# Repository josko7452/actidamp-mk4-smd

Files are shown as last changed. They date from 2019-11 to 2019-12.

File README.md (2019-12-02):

# Actidamp Mk. IV - SMD

Low noise RIAA preamplifier with JFET input and active input impedance (to mitigate Johnson noise)

## Schematics

* **Main board** - [pdf link](https://github.com/josko7452/actidamp-mk4-smd/releases/download/2019.11.5/main-pcb.pdf)
* **Power supply** - [pdf link](https://github.com/josko7452/actidamp-mk4-smd/releases/download/2019.11.5/psu-brick.pdf)
* **Front & Back panel** - [pdf link](https://github.com/josko7452/actidamp-mk4-smd/releases/download/2019.11.5/panels.pdf)

## Pictures

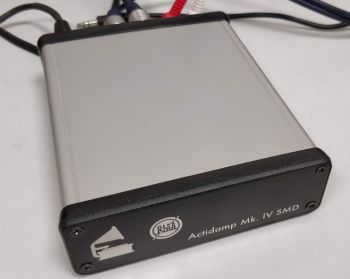
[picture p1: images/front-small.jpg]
front

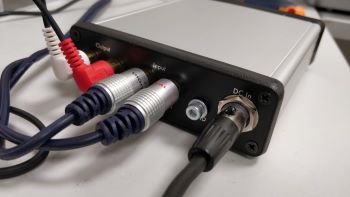
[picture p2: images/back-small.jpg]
back

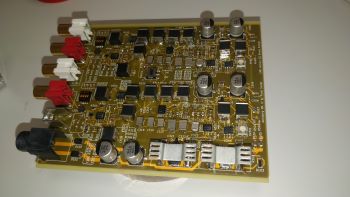
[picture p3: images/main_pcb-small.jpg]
main-pcb

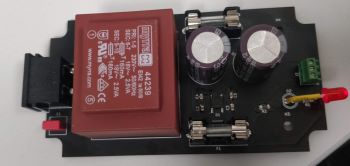
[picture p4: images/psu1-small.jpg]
psu1

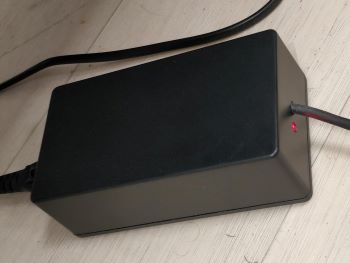
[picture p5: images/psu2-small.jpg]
psu2


## Getting Started

To build this just download Gerbers from release page and hand-off to your favourtie PCB manufacturer.
I have tested it with JLC PCB. But it has no crazy requirements besides the mainboard is 4 layer.

(If you want BOM, download KiCad and generate it from the Schematic, you will likely change parts anyway
dependig on accessibility.. you can shoot me a message and I will send you the Mouser part list from
my order history if you wish)

## Structure

There are 3 KiCad project for each PCB. i.e. *'main-pcb'*, *'panels'* and *'psu-brick'*.
Also there is LTSpice simulation in 'ltspice' subfolder.
Other than that it also cointains KiCad libraries used as submodules (kicad-footprints and kicad-symbols)

## Authors

* **Pavel Dudek** - *Original THT version* - [Amaterske radio 94-06](https://archive.org/stream/Amaterske_radio_1994/94-06#page/n19)
* **Bruno Kremel [me]** - *Modified to SMD and using different JFET*

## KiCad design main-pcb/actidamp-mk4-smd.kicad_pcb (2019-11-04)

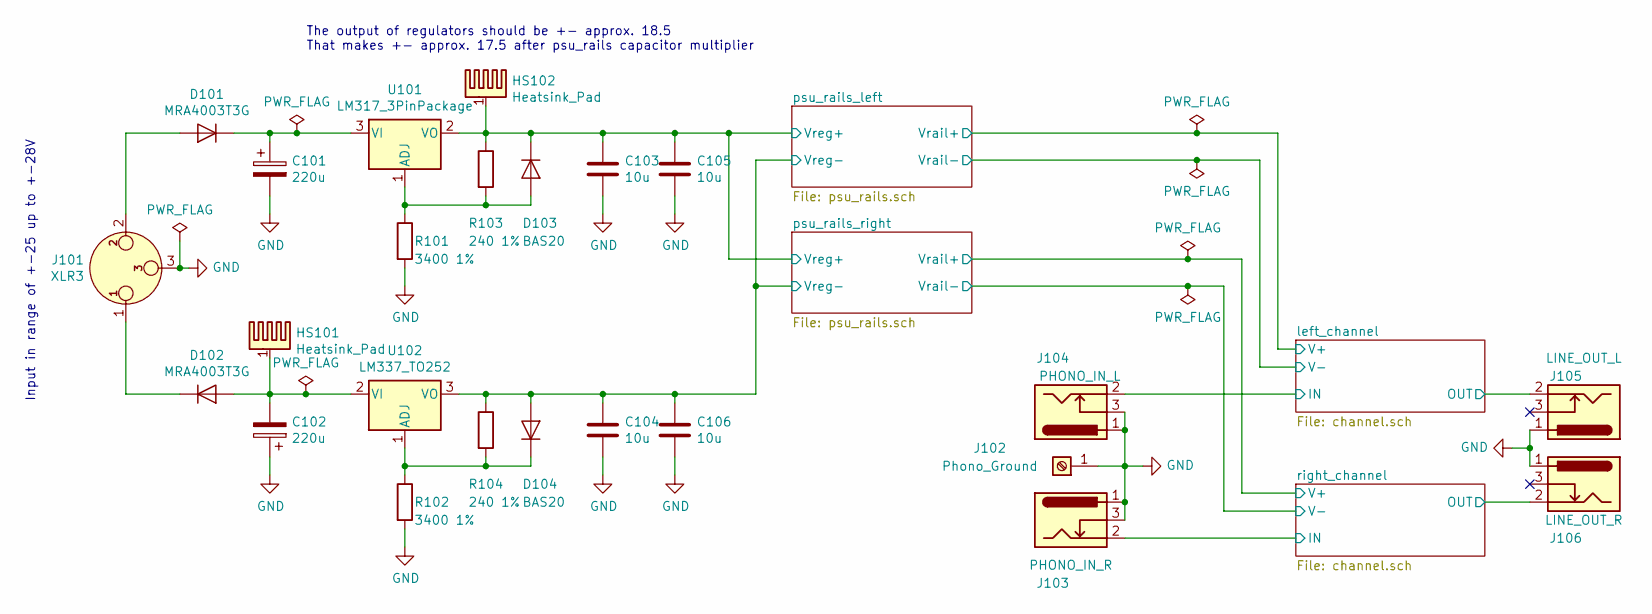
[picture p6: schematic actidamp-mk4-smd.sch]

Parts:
C101, C102: 220u; CP_Elec_8x10.5; Part number EEE1EA221UP
C103, C104, C105, C106: 10u; C_1206_3216Metric_Pad1.42x1.75mm_HandSolder; Part number C1206C106K3PACTU
D101, D102: MRA4003T3G; D_SMA; Part number MRA4003T3G
D103, D104: BAS20; D_SOT-23_ANK; Part number BAS20
HS101, HS102: Heatsink_Pad; Heatsink_TO252_573100; Part number FK 244 13 D PAK
J101: XLR3; MiniXLR_TRAPC3M1X; Part number TRAPC3MX
J102: Phono_Ground; SCREW_TERMINAL_SCTM4RA; Part number SCRTM4RA
J103: PHONO_IN_L; RCA_x1_PJRAN1X1U; Part number PJRAN1X1U02AUX
J104: PHONO_IN_R; RCA_x1_PJRAN1X1U; Part number PJRAN1X1U03AUX
J105: LINE_OUT_L; RCA_x1_PJRAN1X1U; Part number PJRAN1X1U02AUX
J106: LINE_OUT_R; RCA_x1_PJRAN1X1U; Part number PJRAN1X1U03AUX
R101, R102: 3400 1%; R_0603_1608Metric_Pad1.05x0.95mm_HandSolder; Part number MCWF06R3401BTL
R103, R104: 240 1%; R_0603_1608Metric_Pad1.05x0.95mm_HandSolder; Part number ERA3AEB241V
U101: LM317_3PinPackage; TO-252-3_TabPin2; Part number LM317MDTX
U102: LM337_TO252; TO-252-3_TabPin2; Part number LM337KVURG3

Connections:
/left_channel/IN: J103.2; also elsewhere on the board
/left_channel/OUT: J105.2; also elsewhere on the board
/psu_rails_left/Vreg+: C103.1, C105.1, D103.1 (K), HS102.1, R103.1, U101.2 (VO); also elsewhere on the board
/psu_rails_left/Vreg-: C104.2, C106.2, D104.2 (A), R104.1, U102.3 (VO); also elsewhere on the board
/right_channel/IN: J104.2; also elsewhere on the board
/right_channel/OUT: J106.2; also elsewhere on the board
GND: C101.2, C102.1, C103.2, C104.1, C105.2, C106.1, J101.3, J102.1, J103.1, J103.3, J104.1, J104.3, J105.1, J106.1, R101.2, R102.2; also elsewhere on the board
unnamed: C101.1, D101.1 (K), U101.3 (VI)
unnamed: C102.2, D102.2 (A), HS101.1, U102.2 (VI)
unnamed: D101.2 (A), J101.2
unnamed: D102.1 (K), J101.1
unnamed: D103.2 (A), R101.1, R103.2, U101.1 (ADJ)
unnamed: D104.1 (K), R102.1, R104.2, U102.1 (ADJ)

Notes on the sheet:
The output of regulators should be +- approx. 18.5 That makes +- approx. 17.5 after psu_rails capacitor multiplier
Input in range of +-25 up to +-28V

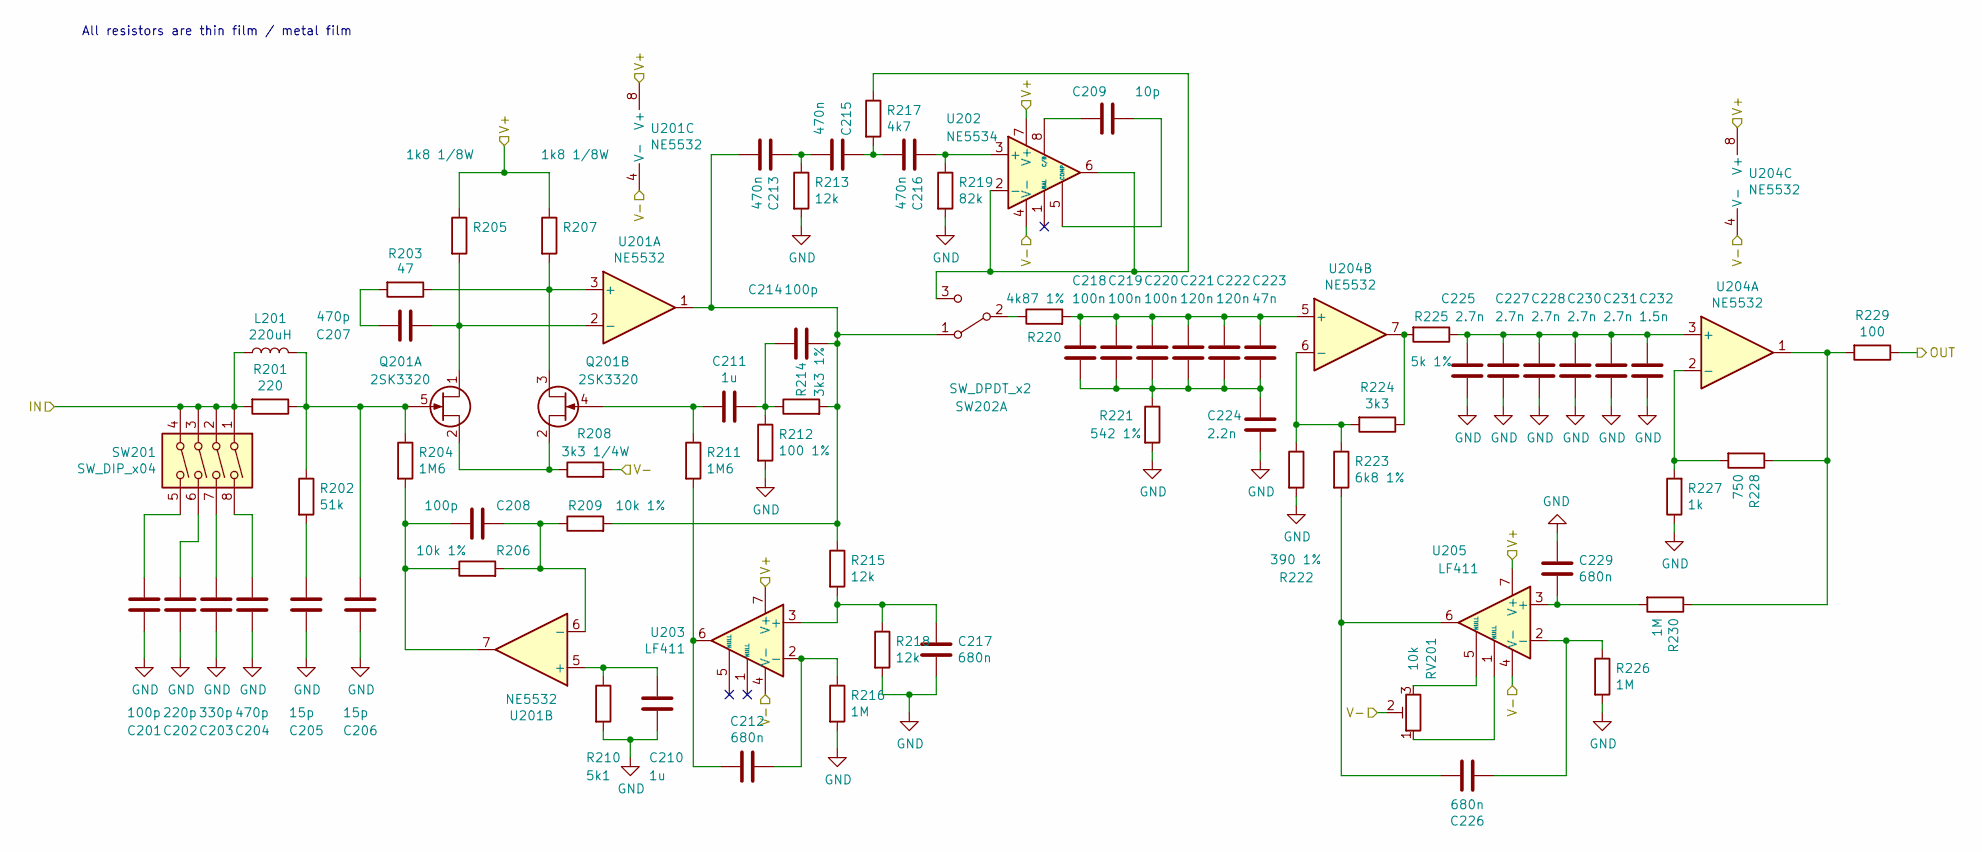
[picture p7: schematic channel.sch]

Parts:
C201, C208, C214: 100p; C_0603_1608Metric_Pad1.05x0.95mm_HandSolder; Part number MC0603N101J500CT
C202: 220p; C_0603_1608Metric_Pad1.05x0.95mm_HandSolder; Part number 06035A221JAT2A
C203: 330p; C_0603_1608Metric_Pad1.05x0.95mm_HandSolder; Part number MC0603N331J500CT
C204, C207: 470p; C_0603_1608Metric_Pad1.05x0.95mm_HandSolder; Part number VJ0603A471JXACW1BC
C205, C206: 15p; C_0603_1608Metric_Pad1.05x0.95mm_HandSolder; Part number MC0603N150J500CT
C209: 10p; C_0603_1608Metric_Pad1.05x0.95mm_HandSolder; Part number MC0603N100J500CT
C210, C211: 1u; C_2824_7260Metric_Pad3.20x4.45mm_HandSolder; Part number SMDIC04100TB00KQ00
C212, C217, C226, C229: 680n; C_2824_7260Metric_Pad3.20x4.45mm_HandSolder; Part number SMDIC03680TB00KQ00
C213, C215, C216: 470n; C_2824_7260Metric_Pad3.20x4.45mm_HandSolder; Part number SMDIC03470TB00MQ00
C218, C219, C220: 100n; C_1913_4833Metric_Pad1.3x3.00mm_HandSolder; Part number ECHU1H104GX9
C221, C222: 120n; C_2416_6041Metric_Pad1.5x3.8mm_HandSolder; Part number ECHU1H124GX9
C223: 47n; C_1913_4833Metric_Pad1.3x3.00mm_HandSolder; Part number ECHU1H473GX9
C224: 2.2n; C_0805_2012Metric_Pad1.15x1.1mm_HandSolder; Part number ECHU1H222GX5
C225, C227, C228, C230, C231: 2.7n; C_0805_2012Metric_Pad1.15x1.1mm_HandSolder; Part number ECHU1H272GX5
C232: 1.5n; C_0805_2012Metric_Pad1.15x1.1mm_HandSolder; Part number ECHU1H152GX5
L201: 220uH; L_NLFV32_Pad1.2x2.0mm_HandSolder; Part number NLFV32T-221K-EF
Q201: 2SK3320; SOT-353_SC-70-5_Handsoldering; Part number 2SK3320
R201: 220; R_0603_1608Metric_Pad1.05x0.95mm_HandSolder; Part number ERA3AEB221V
R202: 51k; R_0603_1608Metric_Pad1.05x0.95mm_HandSolder; Part number ERA3AEB513V
R203: 47; R_0603_1608Metric_Pad1.05x0.95mm_HandSolder; Part number RT0603FRE0747RL
R204, R211: 1M6; R_0805_2012Metric_Pad1.15x1.40mm_HandSolder; Part number 1-1614959-2
R205, R207: 1k8 1/8W; R_0805_2012Metric_Pad1.15x1.40mm_HandSolder; Part number RT0805FRE071K8L
R206, R209: 10k 1%; R_0603_1608Metric_Pad1.05x0.95mm_HandSolder; Part number RT0603WRE0710KL
R208: 3k3 1/4W; R_1206_3216Metric_Pad1.42x1.75mm_HandSolder; Part number ERA8ARB332V
R210: 5k1; R_0603_1608Metric_Pad1.05x0.95mm_HandSolder; Part number ERA3AEB512V
R212: 100 1%; R_0603_1608Metric_Pad1.05x0.95mm_HandSolder; Part number RT0603FRE07100RL
R213, R215, R218: 12k; R_0603_1608Metric_Pad1.05x0.95mm_HandSolder; Part number ERA3AEB123V
R214: 3k3 1%; R_0603_1608Metric_Pad1.05x0.95mm_HandSolder; Part number RT0603FRE073K3L
R216, R226, R230: 1M; R_0603_1608Metric_Pad1.05x0.95mm_HandSolder; Part number MCT06030C1004FP500
R217: 4k7; R_0603_1608Metric_Pad1.05x0.95mm_HandSolder; Part number RT0603FRE074K7L
R219: 82k; R_0603_1608Metric_Pad1.05x0.95mm_HandSolder; Part number ERA3AEB823V
R220: 4k87 1%; R_0603_1608Metric_Pad1.05x0.95mm_HandSolder; Part number CPF0603F4K87C1
R221: 542 1%; R_0603_1608Metric_Pad1.05x0.95mm_HandSolder; Part number RN73H1JTTD5420B50
R222: 390 1%; R_0603_1608Metric_Pad1.05x0.95mm_HandSolder; Part number RT0603FRE07390RL
R223: 6k8 1%; R_0603_1608Metric_Pad1.05x0.95mm_HandSolder; Part number RT0603FRE076K8L
R224: 3k3; R_0603_1608Metric_Pad1.05x0.95mm_HandSolder; Part number RT0603FRE073K3L
R225: 5k 1%; R_0603_1608Metric_Pad1.05x0.95mm_HandSolder; Part number RT0603BRE075KL
R227: 1k; R_0603_1608Metric_Pad1.05x0.95mm_HandSolder; Part number RT0603FRE071KL
R228: 750; R_0603_1608Metric_Pad1.05x0.95mm_HandSolder; Part number MCT06030C7500FP500
R229: 100; R_0603_1608Metric_Pad1.05x0.95mm_HandSolder; Part number MCT06030C1000FP500
RV201: 10k; Potentiometer_Vishay_TS53YJ_Vertical; Part number TS53YJ103MR10
SW201: SW_DIP_x04; SW_DIP_SPSTx04_Slide_TE_1571983-5_W6.2mm_P1.27mm; Part number 1571983-5
SW202: SW_DPDT_x2; Wurth_452403012014; Part number 452403012014
U201, U204: NE5532; SOIC-8_3.9x4.9mm_P1.27mm; Part number NE5532DR
U202: NE5534; SOIC-8_3.9x4.9mm_P1.27mm; Part number NE5534ADG
U203, U205: LF411; SOIC-8_3.9x4.9mm_P1.27mm; Part number LF411CD

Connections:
/left_channel/IN: L201.1, R201.2, SW201.1, SW201.2, SW201.3, SW201.4; also elsewhere on the board
/left_channel/OUT: R229.1; also elsewhere on the board
/left_channel/V+: R205.1, R207.1, U201.8 (V+), U202.7 (V+), U203.7 (V+), U204.8 (V+), U205.7 (V+); also elsewhere on the board
/left_channel/V-: R208.2, RV201.2, U201.4 (V-), U202.4 (V-), U203.4 (V-), U204.4 (V-), U205.4 (V-); also elsewhere on the board
GND: C201.2, C202.2, C203.2, C204.2, C205.2, C206.2, C210.2, C217.2, C224.2, C225.2, C227.2, C228.2, C229.1, C230.2, C231.2, C232.2, R210.2, R212.2, R213.2, R216.2, R218.2, R219.2, R221.2, R222.2, R226.2, R227.1; also elsewhere on the board
unnamed: C201.1, SW201.5
unnamed: C202.1, SW201.6
unnamed: C203.1, SW201.7
unnamed: C204.1, SW201.8
unnamed: C205.1, R202.2
unnamed: C206.1, L201.2, Q201.5 (G), R201.1, R202.1, R204.1
unnamed: C207.1, Q201.1 (D), R205.2, U201.2 (-)
unnamed: C207.2, R203.2
unnamed: C208.1, R206.2, R209.1, U201.6 (-)
unnamed: C208.2, R204.2, R206.1, U201.7
unnamed: C209.1, U202.5 (COMP)
unnamed: C209.2, U202.8 (C/B)
unnamed: C210.1, R210.1, U201.5 (+)
unnamed: C211.1, C214.2, R212.1, R214.1
unnamed: C211.2, Q201.4 (G), R211.1
unnamed: C212.1, R216.1, U203.2 (-)
unnamed: C212.2, R211.2, U203.6
unnamed: C213.1, C215.2, R213.1
unnamed: C213.2, C214.1, R209.2, R214.2, R215.1, SW202.1 (A), U201.1
unnamed: C215.1, C216.2, R217.2
unnamed: C216.1, R219.1, U202.3 (+)
unnamed: C217.1, R215.2, R218.1, U203.3 (+)
unnamed: C218.1, C219.1, C220.1, C221.1, C222.1, C223.1, R220.2, U204.5 (+)
unnamed: C218.2, C219.2, C220.2, C221.2, C222.2, C223.2, C224.1, R221.1
unnamed: C225.1, C227.1, C228.1, C230.1, C231.1, C232.1, R225.1, U204.3 (+)
unnamed: C226.1, R223.2, U205.6
unnamed: C226.2, R226.1, U205.2 (-)
unnamed: C229.2, R230.2, U205.3 (+)
unnamed 59: SW202.4 (A); also elsewhere on the board
unnamed: Q201.2 (S), R208.1
unnamed: Q201.3 (D), R203.1, R207.2, U201.3 (+)
unnamed: R217.1, SW202.3 (C), U202.2 (-), U202.6
unnamed: R220.1, SW202.2 (B)
unnamed: R222.1, R223.1, R224.2, U204.6 (-)
unnamed: R224.1, R225.2, U204.7
unnamed: R227.2, R228.2, U204.2 (-)
unnamed: R228.1, R229.2, R230.1, U204.1
unnamed 97: SW202.6 (C); also elsewhere on the board
unnamed 98: SW202.5 (B); also elsewhere on the board
unnamed: RV201.1, U205.1 (NULL)
unnamed: RV201.3, U205.5 (NULL)

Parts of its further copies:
C301, C308, C314: 100p; C_0603_1608Metric_Pad1.05x0.95mm_HandSolder; Part number MC0603N101J500CT
C302: 220p; C_0603_1608Metric_Pad1.05x0.95mm_HandSolder; Part number 06035A221JAT2A
C303: 330p; C_0603_1608Metric_Pad1.05x0.95mm_HandSolder; Part number MC0603N331J500CT
C304, C307: 470p; C_0603_1608Metric_Pad1.05x0.95mm_HandSolder; Part number VJ0603A471JXACW1BC
C305, C306: 15p; C_0603_1608Metric_Pad1.05x0.95mm_HandSolder; Part number MC0603N150J500CT
C309: 10p; C_0603_1608Metric_Pad1.05x0.95mm_HandSolder; Part number MC0603N100J500CT
C310, C311: 1u; C_2824_7260Metric_Pad3.20x4.45mm_HandSolder; Part number SMDIC04100TB00KQ00
C312, C317, C326, C329: 680n; C_2824_7260Metric_Pad3.20x4.45mm_HandSolder; Part number SMDIC03680TB00KQ00
C313, C315, C316: 470n; C_2824_7260Metric_Pad3.20x4.45mm_HandSolder; Part number SMDIC03470TB00MQ00
C318, C319, C320: 100n; C_1913_4833Metric_Pad1.3x3.00mm_HandSolder; Part number ECHU1H104GX9
C321, C322: 120n; C_2416_6041Metric_Pad1.5x3.8mm_HandSolder; Part number ECHU1H124GX9
C323: 47n; C_1913_4833Metric_Pad1.3x3.00mm_HandSolder; Part number ECHU1H473GX9
C325, C327, C328, C330, C331: 2.7n; C_0805_2012Metric_Pad1.15x1.1mm_HandSolder; Part number ECHU1H272GX5
C332: 1.5n; C_0805_2012Metric_Pad1.15x1.1mm_HandSolder; Part number ECHU1H152GX5
L301: 220uH; L_NLFV32_Pad1.2x2.0mm_HandSolder; Part number NLFV32T-221K-EF
Q301: 2SK3320; SOT-353_SC-70-5_Handsoldering; Part number 2SK3320
R301: 220; R_0603_1608Metric_Pad1.05x0.95mm_HandSolder; Part number ERA3AEB221V
R302: 51k; R_0603_1608Metric_Pad1.05x0.95mm_HandSolder; Part number ERA3AEB513V
R303: 47; R_0603_1608Metric_Pad1.05x0.95mm_HandSolder; Part number RT0603FRE0747RL
R304, R311: 1M6; R_0805_2012Metric_Pad1.15x1.40mm_HandSolder; Part number 1-1614959-2
R305, R307: 1k8 1/8W; R_0805_2012Metric_Pad1.15x1.40mm_HandSolder; Part number RT0805FRE071K8L
R306, R309: 10k 1%; R_0603_1608Metric_Pad1.05x0.95mm_HandSolder; Part number RT0603WRE0710KL
R308: 3k3 1/4W; R_1206_3216Metric_Pad1.42x1.75mm_HandSolder; Part number ERA8ARB332V
R310: 5k1; R_0603_1608Metric_Pad1.05x0.95mm_HandSolder; Part number ERA3AEB512V
R312: 100 1%; R_0603_1608Metric_Pad1.05x0.95mm_HandSolder; Part number RT0603FRE07100RL
R313, R315, R318: 12k; R_0603_1608Metric_Pad1.05x0.95mm_HandSolder; Part number ERA3AEB123V
R314: 3k3 1%; R_0603_1608Metric_Pad1.05x0.95mm_HandSolder; Part number RT0603FRE073K3L
R316, R326, R330: 1M; R_0603_1608Metric_Pad1.05x0.95mm_HandSolder; Part number MCT06030C1004FP500
R317: 4k7; R_0603_1608Metric_Pad1.05x0.95mm_HandSolder; Part number RT0603FRE074K7L
R319: 82k; R_0603_1608Metric_Pad1.05x0.95mm_HandSolder; Part number ERA3AEB823V
R320: 4k87 1%; R_0603_1608Metric_Pad1.05x0.95mm_HandSolder; Part number CPF0603F4K87C1
R321: 542 1%; R_0603_1608Metric_Pad1.05x0.95mm_HandSolder; Part number RN73H1JTTD5420B50
R322: 390 1%; R_0603_1608Metric_Pad1.05x0.95mm_HandSolder; Part number RT0603FRE07390RL
R323: 6k8 1%; R_0603_1608Metric_Pad1.05x0.95mm_HandSolder; Part number RT0603FRE076K8L
R324: 3k3; R_0603_1608Metric_Pad1.05x0.95mm_HandSolder; Part number RT0603FRE073K3L
R325: 5k 1%; R_0603_1608Metric_Pad1.05x0.95mm_HandSolder; Part number RT0603BRE075KL
R327: 1k; R_0603_1608Metric_Pad1.05x0.95mm_HandSolder; Part number RT0603FRE071KL
R328: 750; R_0603_1608Metric_Pad1.05x0.95mm_HandSolder; Part number MCT06030C7500FP500
R329: 100; R_0603_1608Metric_Pad1.05x0.95mm_HandSolder; Part number MCT06030C1000FP500
RV301: 10k; Potentiometer_Vishay_TS53YJ_Vertical; Part number TS53YJ103MR10
SW301: SW_DIP_x04; SW_DIP_SPSTx04_Slide_TE_1571983-5_W6.2mm_P1.27mm; Part number 1571983-5
U301, U304: NE5532; SOIC-8_3.9x4.9mm_P1.27mm; Part number NE5532DR
U302: NE5534; SOIC-8_3.9x4.9mm_P1.27mm; Part number NE5534ADG
U303, U305: LF411; SOIC-8_3.9x4.9mm_P1.27mm; Part number LF411CD

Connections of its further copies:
/right_channel/IN: L301.1, R301.2, SW301.1, SW301.2, SW301.3, SW301.4; also elsewhere on the board
/right_channel/OUT: R329.1; also elsewhere on the board
/right_channel/V+: R305.1, R307.1, U301.8 (V+), U302.7 (V+), U303.7 (V+), U304.8 (V+), U305.7 (V+); also elsewhere on the board
/right_channel/V-: R308.2, RV301.2, U301.4 (V-), U302.4 (V-), U303.4 (V-), U304.4 (V-), U305.4 (V-); also elsewhere on the board
GND: C301.2, C302.2, C303.2, C304.2, C305.2, C306.2, C310.2, C317.2, C325.2, C327.2, C328.2, C329.1, C330.2, C331.2, C332.2, R310.2, R312.2, R313.2, R316.2, R318.2, R319.2, R321.2, R322.2, R326.2, R327.1; also elsewhere on the board
unnamed: C301.1, SW301.5
unnamed: C302.1, SW301.6
unnamed: C303.1, SW301.7
unnamed: C304.1, SW301.8
unnamed: C305.1, R302.2
unnamed: C306.1, L301.2, Q301.5 (G), R301.1, R302.1, R304.1
unnamed: C307.1, Q301.1 (D), R305.2, U301.2 (-)
unnamed: C307.2, R303.2
unnamed: C308.1, R306.2, R309.1, U301.6 (-)
unnamed: C308.2, R304.2, R306.1, U301.7
unnamed: C309.1, U302.5 (COMP)
unnamed: C309.2, U302.8 (C/B)
unnamed: C310.1, R310.1, U301.5 (+)
unnamed: C311.1, C314.2, R312.1, R314.1
unnamed: C311.2, Q301.4 (G), R311.1
unnamed: C312.1, R316.1, U303.2 (-)
unnamed: C312.2, R311.2, U303.6
unnamed: C313.1, C315.2, R313.1
unnamed 59: C313.2, C314.1, R309.2, R314.2, R315.1, U301.1; also elsewhere on the board
unnamed: C315.1, C316.2, R317.2
unnamed: C316.1, R319.1, U302.3 (+)
unnamed: C317.1, R315.2, R318.1, U303.3 (+)
unnamed: C318.1, C319.1, C320.1, C321.1, C322.1, C323.1, R320.2, U304.5 (+)
unnamed 64: C318.2, C319.2, C320.2, C321.2, C322.2, C323.2, R321.1; also elsewhere on the board
unnamed: C325.1, C327.1, C328.1, C330.1, C331.1, C332.1, R325.1, U304.3 (+)
unnamed: C326.1, R323.2, U305.6
unnamed: C326.2, R326.1, U305.2 (-)
unnamed: C329.2, R330.2, U305.3 (+)
unnamed: Q301.2 (S), R308.1
unnamed: Q301.3 (D), R303.1, R307.2, U301.3 (+)
unnamed 97: R317.1, U302.2 (-), U302.6; also elsewhere on the board
unnamed 98: R320.1; also elsewhere on the board
unnamed: R322.1, R323.1, R324.2, U304.6 (-)
unnamed: R324.1, R325.2, U304.7
unnamed: R327.2, R328.2, U304.2 (-)
unnamed: R328.1, R329.2, R330.1, U304.1
unnamed: RV301.1, U305.1 (NULL)
unnamed: RV301.3, U305.5 (NULL)

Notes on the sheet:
All resistors are thin film / metal film

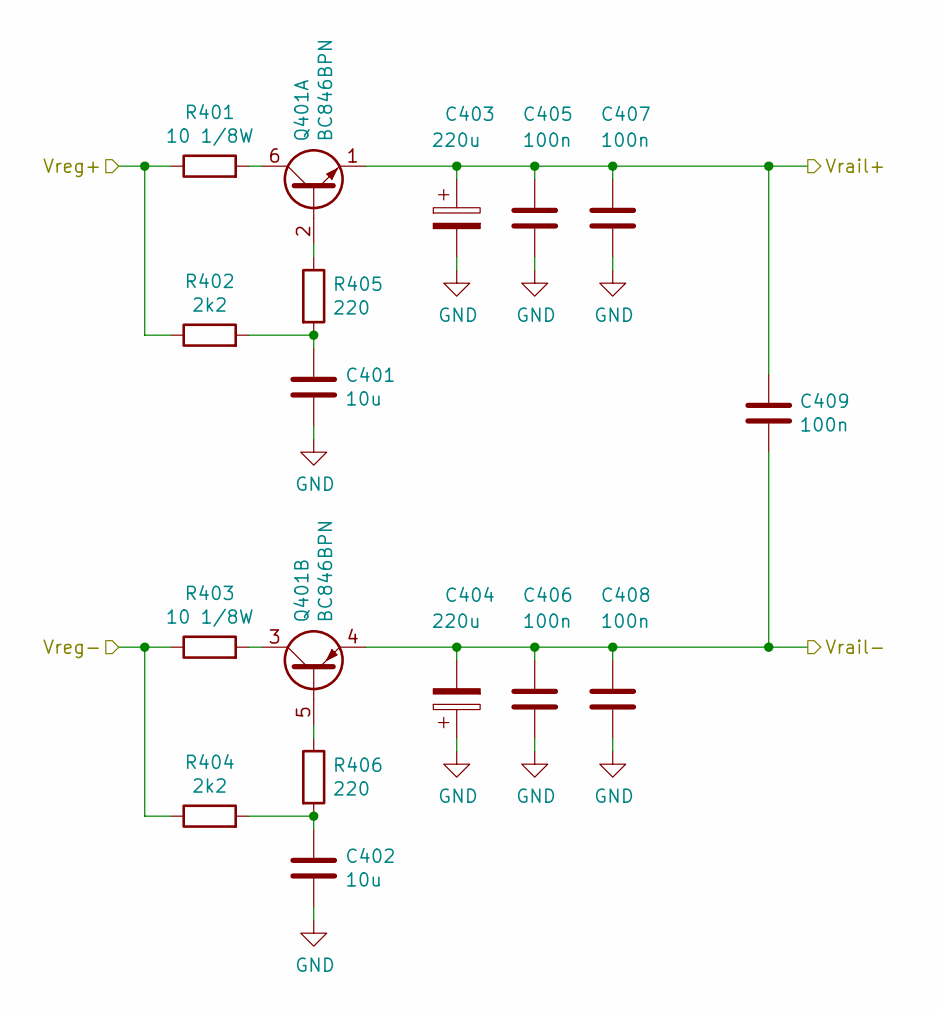
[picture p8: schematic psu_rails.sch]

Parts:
C401, C402: 10u; C_1206_3216Metric_Pad1.42x1.75mm_HandSolder; Part number C1206C106K3PACTU
C403, C404: 220u; CP_Elec_8x10.5; Part number EEE1EA221UP
C405, C406, C407, C408, C409: 100n; C_0603_1608Metric_Pad1.05x0.95mm_HandSolder; Part number VJ0603Y104KXACW1BC
Q401: BC846BPN; SOT-363_SC-70-6; Part number BC846BPN
R401, R403: 10 1/8W; R_0805_2012Metric_Pad1.15x1.40mm_HandSolder; Part number MCWF08U10RBTL
R402, R404: 2k2; R_0603_1608Metric_Pad1.05x0.95mm_HandSolder; Part number RT0603FRE072K2L
R405, R406: 220; R_0603_1608Metric_Pad1.05x0.95mm_HandSolder; Part number ERA3AEB221V

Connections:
/left_channel/V+: C403.1, C405.1, C407.1, C409.1, Q401.1 (E1); also elsewhere on the board
/left_channel/V-: C404.2, C406.1, C408.1, C409.2, Q401.4 (E2); also elsewhere on the board
/psu_rails_left/Vreg+: R401.1, R402.1; also elsewhere on the board
/psu_rails_left/Vreg-: R403.1, R404.1; also elsewhere on the board
GND: C401.2, C402.1, C403.2, C404.1, C405.2, C406.2, C407.2, C408.2; also elsewhere on the board
unnamed: C401.1, R402.2, R405.2
unnamed: C402.2, R404.2, R406.2
unnamed: Q401.2 (B1), R405.1
unnamed: Q401.3 (C2), R403.2
unnamed: Q401.5 (B2), R406.1
unnamed: Q401.6 (C1), R401.2

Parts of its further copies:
C501, C502: 10u; C_1206_3216Metric_Pad1.42x1.75mm_HandSolder; Part number C1206C106K3PACTU
C503, C504: 220u; CP_Elec_8x10.5; Part number EEE1EA221UP
C505, C506, C507, C508, C509: 100n; C_0603_1608Metric_Pad1.05x0.95mm_HandSolder; Part number VJ0603Y104KXACW1BC
Q501: BC846BPN; SOT-363_SC-70-6; Part number BC846BPN
R501, R503: 10 1/8W; R_0805_2012Metric_Pad1.15x1.40mm_HandSolder; Part number MCWF08U10RBTL
R502, R504: 2k2; R_0603_1608Metric_Pad1.05x0.95mm_HandSolder; Part number RT0603FRE072K2L
R505, R506: 220; R_0603_1608Metric_Pad1.05x0.95mm_HandSolder; Part number ERA3AEB221V

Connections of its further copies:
/psu_rails_left/Vreg+: R501.1, R502.1; also elsewhere on the board
/psu_rails_left/Vreg-: R503.1, R504.1; also elsewhere on the board
/right_channel/V+: C503.1, C505.1, C507.1, C509.1, Q501.1 (E1); also elsewhere on the board
/right_channel/V-: C504.2, C506.1, C508.1, C509.2, Q501.4 (E2); also elsewhere on the board
GND: C501.2, C502.1, C503.2, C504.1, C505.2, C506.2, C507.2, C508.2; also elsewhere on the board
unnamed: C501.1, R502.2, R505.2
unnamed: C502.2, R504.2, R506.2
unnamed: Q501.2 (B1), R505.1
unnamed: Q501.3 (C2), R503.2
unnamed: Q501.5 (B2), R506.1
unnamed: Q501.6 (C1), R501.2

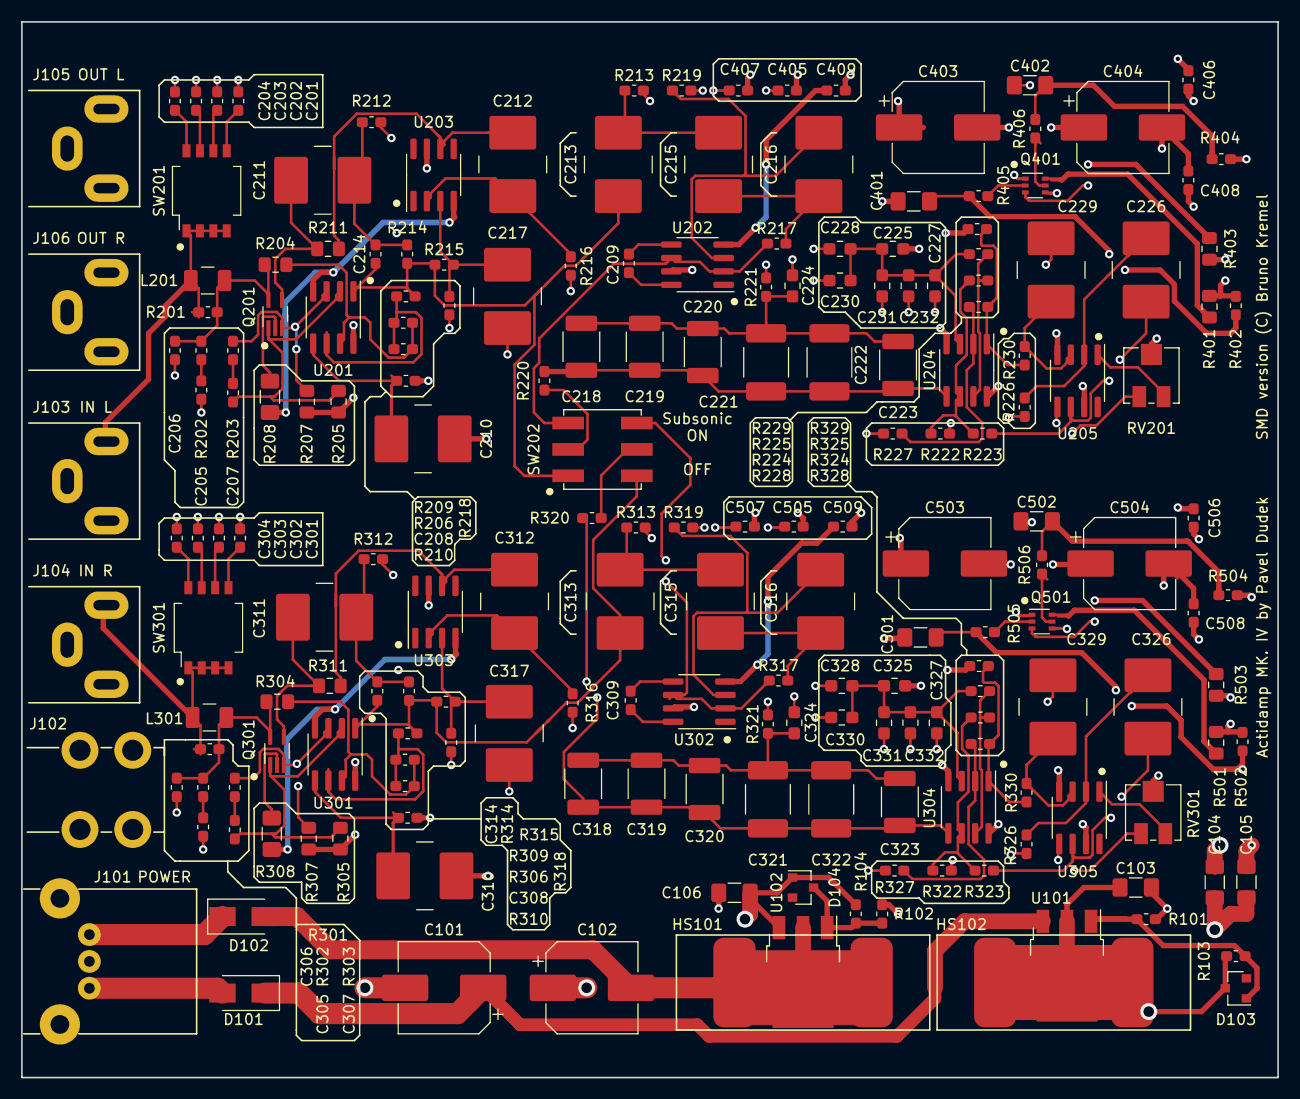
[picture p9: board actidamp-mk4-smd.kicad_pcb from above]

Board: 4 copper layers, 119.0 x 100.0 mm, 199 parts (0 on the bottom side), 105 nets.

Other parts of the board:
C324: 220p; C_0805_2012Metric_Pad1.15x1.1mm_HandSolder

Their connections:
GND: C324.2; also elsewhere on the board
unnamed 64: C324.1; also elsewhere on the board

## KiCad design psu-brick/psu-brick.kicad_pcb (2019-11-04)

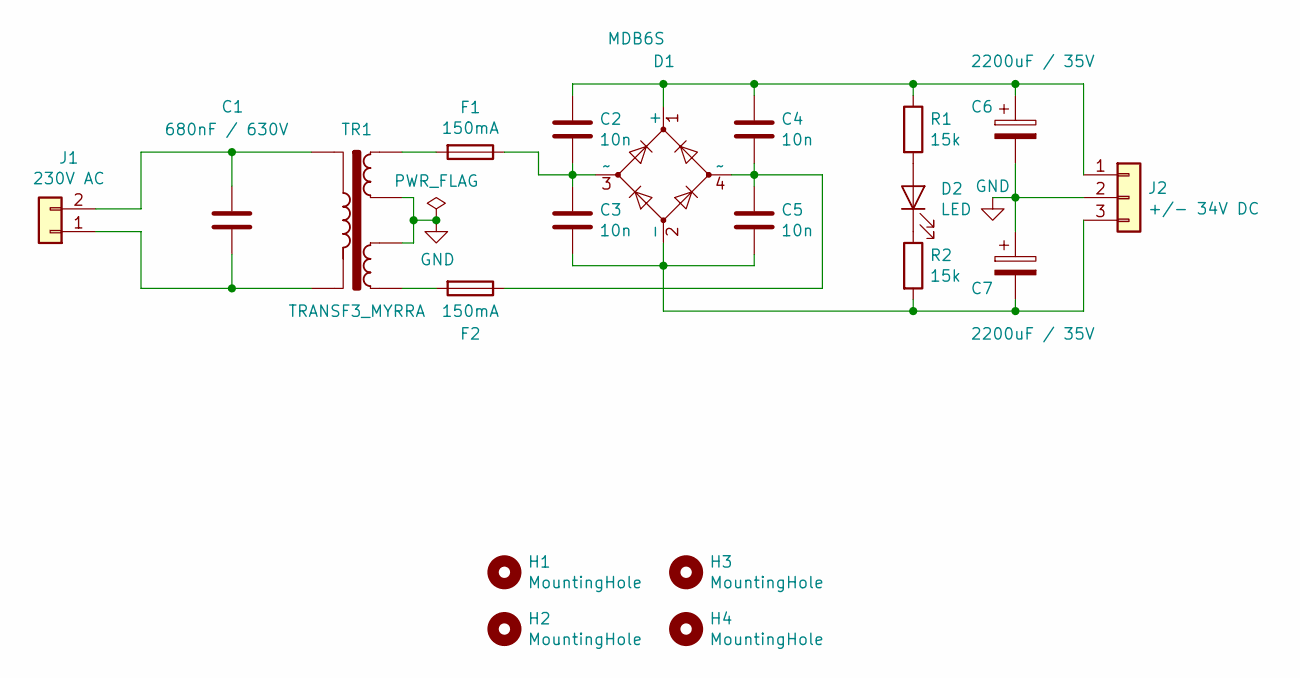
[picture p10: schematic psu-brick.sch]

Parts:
C1: 680nF / 630V; C_Rect_L7.2mm_W7.2mm_P5.00mm_FKS2_FKP2_MKS2_MKP2; Part number MKP2J016801C00KSSD
C2, C3, C4, C5: 10n; C_0805_2012Metric_Pad1.15x1.40mm_HandSolder
C6, C7: 2200uF / 35V; CP_Radial_D16.0mm_P7.50mm
D1: MDB6S
D2: LED; LED_D5.0mm; Part number LTL2R3KRD-EM
F1, F2: 150mA; Fuseholder_Cylinder-5x20mm_Schurter_0031_8201_Horizontal_Op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; Part number 0031.8201
H1, H2, H3, H4: MountingHole; MountingHole_3.5mm
J1: 230V AC; AC_entry_770W-X2; Part number 770W-X2/10
J2: +/- 34V DC; TerminalBlock_TE_282834-3_1x03_P2.54mm_Horizontal
R1, R2: 15k; R_1206_3216Metric_Pad1.42x1.75mm_HandSolder
TR1: TRANSF3_MYRRA; Transformer_Myrra_44x

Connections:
GND: C6.2, C7.1, J2.2, TR1.7, TR1.9
unnamed: C1.1, J1.2, TR1.1
unnamed: C1.2, J1.1, TR1.5
unnamed: C2.1, C4.1, C6.1, D1.1 (+), J2.1, R1.1
unnamed: C2.2, C3.1, D1.3 (~~), F1.1
unnamed: C3.2, C5.2, C7.2, D1.2 (-), J2.3, R2.2
unnamed: C4.2, C5.1, D1.4 (~~), F2.1
unnamed: D2.1 (K), R2.1
unnamed: D2.2 (A), R1.2
unnamed: F1.2, TR1.6
unnamed: F2.2, TR1.10

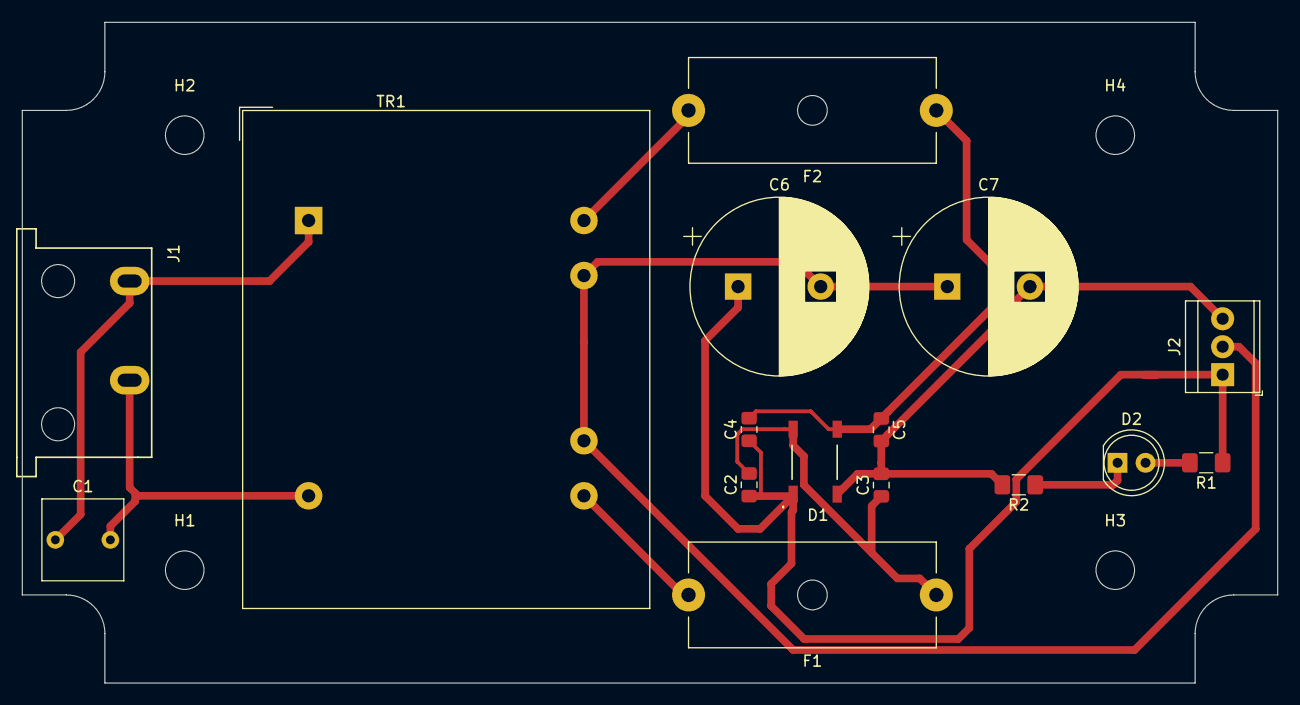
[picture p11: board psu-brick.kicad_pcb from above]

Board: 2 copper layers, 114.0 x 60.0 mm, 20 parts (0 on the bottom side), 11 nets.

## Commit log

2019-02-21 Add initial schematics WIP
    [actidamp-mk4-smd.kicad_pcb, actidamp-mk4-smd.sch]
2019-02-21 Move stuff to hierarchy
    [actidamp-mk4-smd.sch, channel.sch]
2019-02-21 Capture of original actidamp iv
    [actidamp-mk4-smd.sch, channel.sch]
2019-08-26 Assign capacitors, redo hierarchy
    [actidamp-mk4-smd.kicad_pcb, actidamp-mk4-smd.sch, channel.sch]
2019-08-29 All schematics drafted
    [actidamp-mk4-smd.sch, channel.sch, psu_rails.sch]
2019-09-01 Update symbol and footprint library
2019-09-01 Finalise schematics with power supplies and successful ERC
    [actidamp-mk4-smd.sch, channel.sch, psu_rails.sch]
2019-09-01 Finalise BOM
    [actidamp-mk4-smd.sch, channel.sch, psu_rails.sch]
2019-09-02 WIP: Assign footprints
    [actidamp-mk4-smd.sch, channel.sch, psu_rails.sch]
2019-09-03 WIP: Assigning footprints
    [actidamp-mk4-smd.sch, channel.sch, psu_rails.sch]
2019-09-03 Fix ERC errors
    [channel.sch]
2019-09-04 Finish footprints
    [actidamp-mk4-smd.sch, channel.sch]
2019-09-05 Routing.. routing.. routing
    [actidamp-mk4-smd.kicad_pcb, channel.sch]
2019-09-06 All components placed on board
    [actidamp-mk4-smd.kicad_pcb]
2019-09-09 More routing
    [actidamp-mk4-smd.kicad_pcb, actidamp-mk4-smd.sch, channel.sch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]
2019-09-10 All routed
    [actidamp-mk4-smd.kicad_pcb]
2019-10-16 Finish silkscreen
    [actidamp-mk4-smd.kicad_pcb, channel.sch, psu_rails.sch]
2019-10-21 Just layer visibility..
    [actidamp-mk4-smd.kicad_pcb]
2019-10-21 Split to multiple kicad projects
    [actidamp-mk4-smd.kicad_pcb, actidamp-mk4-smd.sch, channel.sch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]
2019-10-21 Add PSU brick
    [psu-brick.kicad_pcb, psu-brick.sch]
2019-10-30 Fix pad for heatsing (it was too small)
2019-10-30 Fix wrong sizes of the SMD switch
2019-10-30 Finish PSU brick
    [psu-brick.kicad_pcb, psu-brick.sch]
2019-10-30 Add panels
    [panels.kicad_pcb, panels.sch]
2019-10-30 Maek board 100mm wide, fix track too close to the edge
    [actidamp-mk4-smd.kicad_pcb]
2019-10-30 Add 1.2mm track width
2019-10-30 After print v5
    [actidamp-mk4-smd.kicad_pcb]
2019-10-30 Some minor modifications
    [actidamp-mk4-smd.kicad_pcb, actidamp-mk4-smd.sch]
2019-11-04 Add custom frontpanel/backpanel footprints
2019-11-04 Update panels with custom footprints
    [panels.kicad_pcb, panels.sch]
2019-11-04 Use only mask layer for FB/BP
    [panels.kicad_pcb]
2019-11-04 Add gerbers folders to gitignore
2019-11-04 Fix unconnected wire
    [psu-brick.kicad_pcb]
2019-11-04 Generate gerbers
    [actidamp-mk4-smd.kicad_pcb]
2019-11-04 Add custom JLC number to bottom silkscreen
    [panels.kicad_pcb]
2019-11-05 Fix stub width for JLCPcb
    [panels.kicad_pcb]
